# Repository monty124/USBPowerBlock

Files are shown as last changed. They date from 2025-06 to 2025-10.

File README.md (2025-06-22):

# USBPowerBlock
Tasmota controlled USB Switching

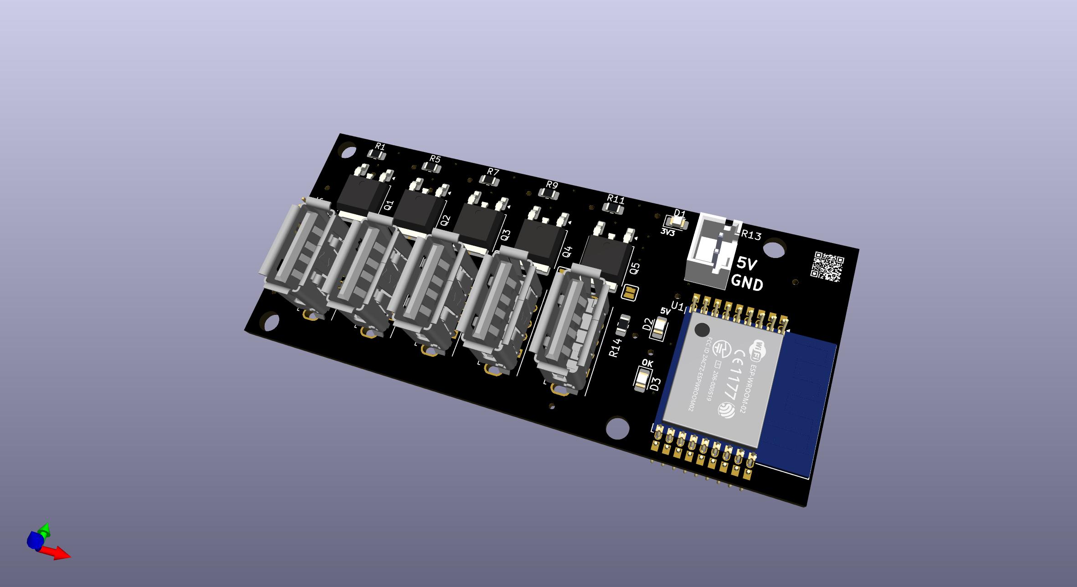
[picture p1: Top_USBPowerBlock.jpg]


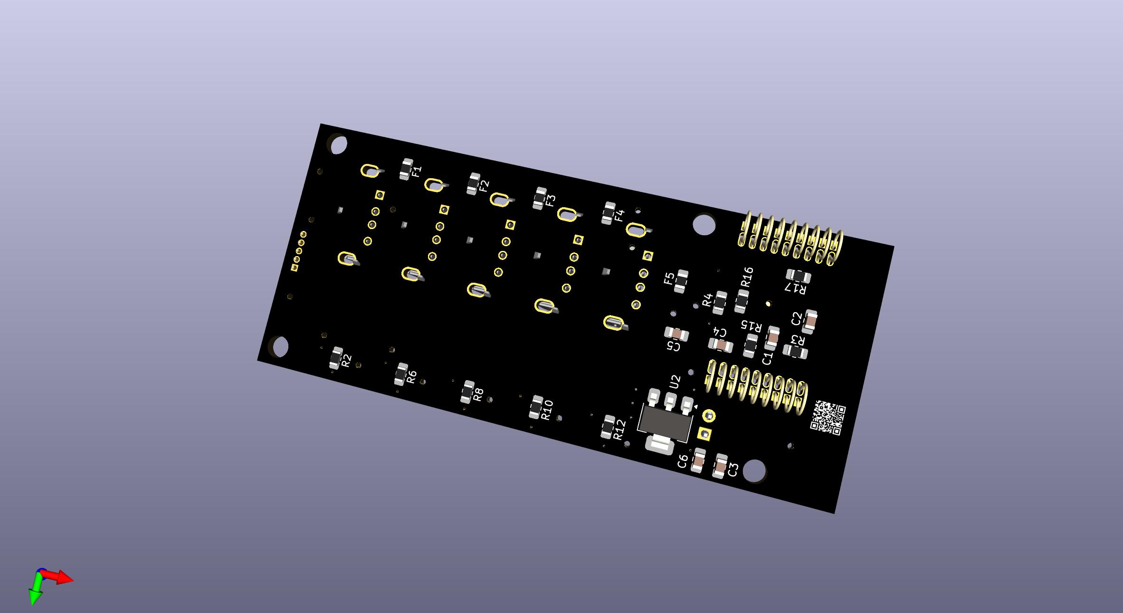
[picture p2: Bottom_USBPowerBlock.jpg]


# Why?

So many things are usb powered but can not or are not able to be integrated easily within Home Assistant; or programable.

Want to turn something on or off automatically? you will need to buy [something else](https://www.aliexpress.com/w/wholesale-TZT-sinilink-USB.html?spm=a2g0o.productlist.search.0)! and it still needs a power source

Want it to be integrated into [Home Assistant](https://www.home-assistant.io/) and or control its [privacy](https://www.voanews.com/a/east-asia-pacific_voa-news-china_cybersecurity-experts-worried-chinese-firms-control-smart-devices/6209815.html)? good luck off the shelf, you may need to [flash it](https://templates.blakadder.com/sinilink_XY-WFUSB.html) (if its supported)

Want more than one device powered from a single power source, you will need a powered hub and multiple other devices, or multiple power sources, this effectively combines 5 [sinilinks'](https://www.aliexpress.com/w/wholesale-TZT-sinilink-USB.html?spm=a2g0o.productlist.search.0) into a single unit.

It has been designed to power a device up to 500mA with the listed BOM, but is flexible (see Options below)

500mA was chosen as a default, as a 5v 2.5A/3A powesupply is very common and affordable (you probably already have one!) and this was intended to switch very low current devices (think, lights, IoT devices, etc)

For more information on USB power draw:

https://en.wikipedia.org/wiki/USB_hardware#Allowable_current_draw

Note, this does not identify itself as a PD or Battery Charging (BC) Device! (yet), technically each port should be limited to 100mA in its current design, but taking some liberties here!

# BOM

[Bill Of Materials](./USBPowerBlock_BOM.csv)

|Reference |Value |Datasheet |Qty |Product_Link|
|---|---|---|---|---|
|C1,C3,C4,C6 |0.1UF-0805-25V-_+80_-20%_|https://www.lcsc.com/datasheet/lcsc_datasheet_2304140030_TORCH-CT41G-0805-2X1-50V-0-1-F-K-N_C126469.pdf |4 |https://www.lcsc.com/product-detail/C126469.html|
|C2,C5 |10UF-0805-16V-10% |https://www.lcsc.com/datasheet/lcsc_datasheet_2409292003_Vishay-Intertech-VJ0805G106KXYTW1BC_C5334346.pdf |2 |https://www.lcsc.com/product-detail/C5334346.html|
|D1 |Blue |https://wmsc.lcsc.com/wmsc/upload/file/pdf/v2/lcsc/2208221800_TCWIN-TC0805GF01-1CSA_C5137315.pdf|1  |https://lcsc.com/product-detail/C5137315.html|
|D2 |Green|https://wmsc.lcsc.com/wmsc/upload/file/pdf/v2/lcsc/2410121920_Lite-On-LTST-C170KGKT_C98221.pdf  |1  |https://lcsc.com/product-detail/C5137315.html|
|D3 |Red  |https://wmsc.lcsc.com/wmsc/upload/file/pdf/v2/lcsc/2504101957_XINGLIGHT-XL-2012SURC_C965812.pdf |1  |https://lcsc.com/product-detail/C5137315.html|
|F1,F2,F3,F4,F5 |JK-SMD0805-020-30V |https://www.lcsc.com/datasheet/lcsc_datasheet_2007081813_Jinrui-Electronic-Materials-Co--JK-SMD0805-020-30V_C516070.pdf|5 |https://www.lcsc.com/product-detail/C516070.html|
|J1,J2,J3,J4,J5 |USB_A | Vertical USB-A |5 |https://www.aliexpress.com/item/1005005865561469.html or https://www.lcsc.com/product-detail/C456015.html|
|J6 |IO |~ |1  |~ |
|J7 |Power_In | XH2.5 |1 |https://www.aliexpress.com/item/1005003137518807.html|
|Q1,Q2,Q3,Q4,Q5 |LMAK15N10 |https://www.lcsc.com/datasheet/lcsc_datasheet_2504180925_VBsemi-Elec-ME15N10-VB_C710010.pdf |5 |https://www.lcsc.com/product-detail/C710010.html|
|R1,R3,R4,R5,R7,R9,R11,R15,R16|10KOHM-0805-1_10W-1% |https://www.lcsc.com/datasheet/lcsc_datasheet_2410121912_TyoHM-RMC080510K5-N_C269724.pdf |9 |https://www.lcsc.com/product-detail/C269724.html|
|R2,R6,R8,R10,R12 |100R |https://www.lcsc.com/datasheet/lcsc_datasheet_2411221126_UNI-ROYAL-Uniroyal-Elec-0805W8F1000T5E_C17408.pdf |5 |https://www.lcsc.com/product-detail/C17408.html|
|R13,R17|68OHM-0805-1_10W-1%|https://www.lcsc.com/datasheet/lcsc_datasheet_2410121912_TyoHM-RMC080510K5-N_C269724.pdf|2  |https://www.lcsc.com/product-detail/C269724.html|
|R14 |470OHM-0805-1_10W-1%|https://www.lcsc.com/datasheet/lcsc_datasheet_2410121912_TyoHM-RMC080510K5-N_C269724.pdf|1  |https://www.lcsc.com/product-detail/C269724.html|
|U1 |ESP-WROOM-02 |https://www.espressif.com/sites/default/files/documentation/0c-esp-wroom-02_datasheet_en.pdf |1 |https://www.lcsc.com/product-detail/C529584.html|
|U2 |AMS1117-3.3 |http://www.advanced-monolithic.com/pdf/ds1117.pdf |1 |https://www.lcsc.com/product-detail/C2992570.html|

Misc Components:

| Product | Example Link | Qty |
| --- | ---| --- |
| 5V 2.5A (min) Power Supply | https://www.wagneronline.com.au/5-volt-3a-switch-mode/power-supplies/power-lighting/smp5v-3a-21r-35234/10297/pd/ | 1 |
| Power Socket 5.5x2.1mm| https://www.aliexpress.com/item/1005002601060281.html | 1 |
| Hook Up Wire ~24AWG | https://www.aliexpress.com/item/1005007278251470.html | 1x Length Red <br> 1x Length Black |
| PCB | [Here](./USBPowerBlock/gerber) | 1 |
| Case | [Here](./Case) | 1 |
| Flexy Pins | https://core-electronics.com.au/flexypin-pack-of-100.html | 18 |

# Options

## I want more current! 

- Swap out your power adaptor for something that can supply your desired current along with approx (at least) ~250mA for the ESP
- Replace F1-F5 with a suitable current rating; 0805 package self healing fuse

  - https://www.lcsc.com/product-detail/C516070.html 500mA
  - https://www.lcsc.com/product-detail/C369151.html 1.5A
  - https://www.lcsc.com/product-detail/C2830234.html 2.2A
  
The MOSFETS are rated to approx 15A each, which is overkill.

## I don't need switched outputs but want like 5 powered USB ports

- leave all components out except J1-J5 + J7
- leave F1-F5 in (and up-rate the fuse value, see above) or replace with 0805 0 Ohm links (https://www.lcsc.com/product-detail/C96345.html)
- solder JP1-JP5
- ensure your power adaptor has enough current

# PCB

Gerber files are available to have printed

- https://www.pcbway.com/
- https://jlcpcb.com/

# 3D Printed Case

STL's are available in this repo to print or have printed

- https://www.pcbway.com/rapid-prototyping/manufacture/?type=2
- https://jlc3dp.com/?source=JLCPCB-top-productbar

# Assembly

TBC

# Tasmota

TBC

# What Next?

Some notes on desired features! (maybe, but probably not)

- Power from a 12V supply?
- Increased power outputs and PD/BC support?
- Compliant USB-C PD Power Source 
- Completed photos
- Flexypin-less design?
- ESP32-C3-WROOM design (ESP-WROOM-02 is EOL) with and without FlexyPin

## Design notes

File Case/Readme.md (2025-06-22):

Yeah this is still a WIP

Print at your own peril!

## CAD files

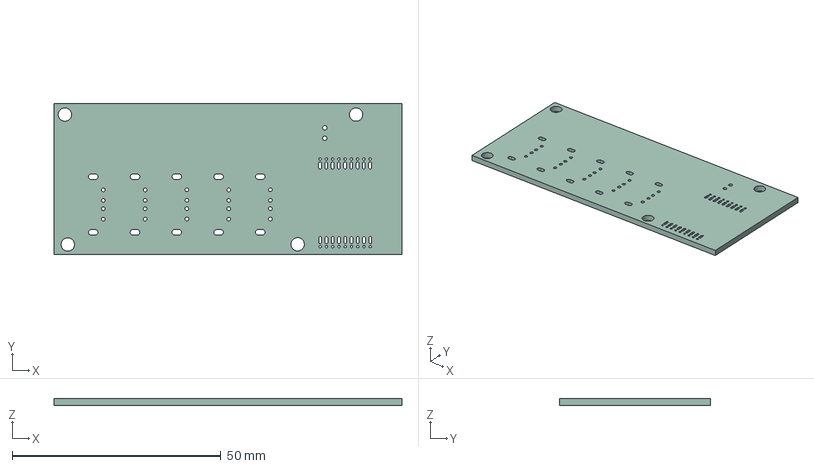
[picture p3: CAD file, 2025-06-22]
3D Models/USBPowerBlock_PCB.step
83.5 x 36.3 x 1.60 mm

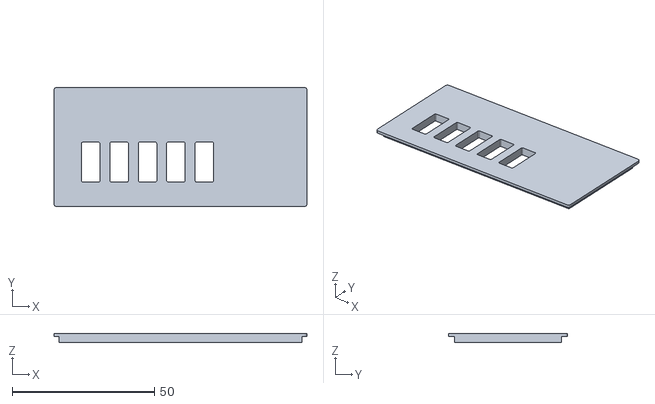
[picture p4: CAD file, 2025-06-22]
Case/USBPowerBlock Case Lid.stl
89.0 x 42.0 x 3.00

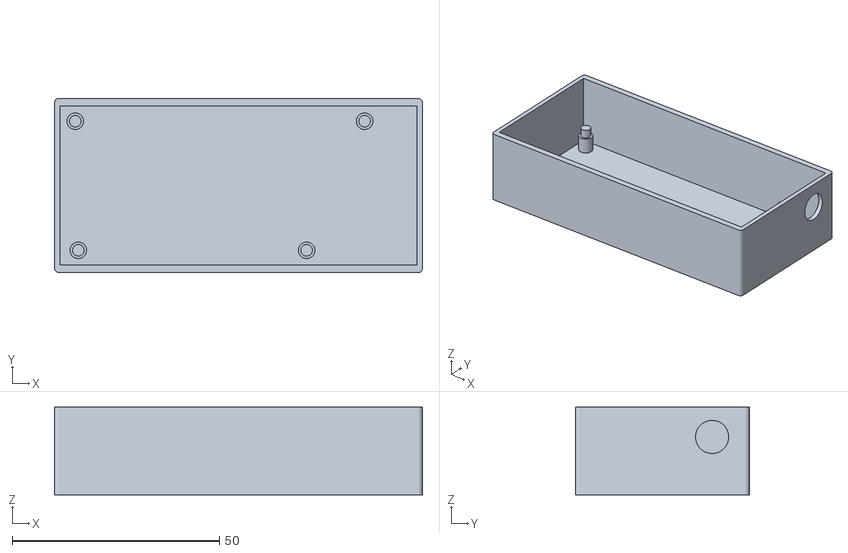
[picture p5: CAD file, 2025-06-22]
Case/USBPowerBlock Case Bottom.stl
88.8 x 42.1 x 21.2

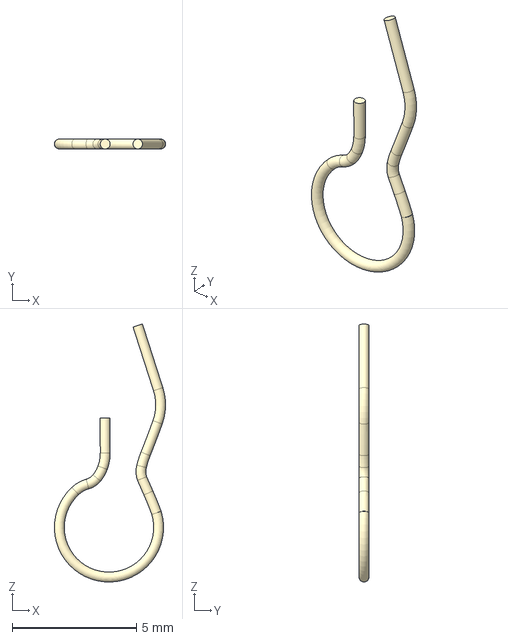
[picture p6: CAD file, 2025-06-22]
Symbols/flexypin.step
4.48 x 0.4 x 10.4 mm

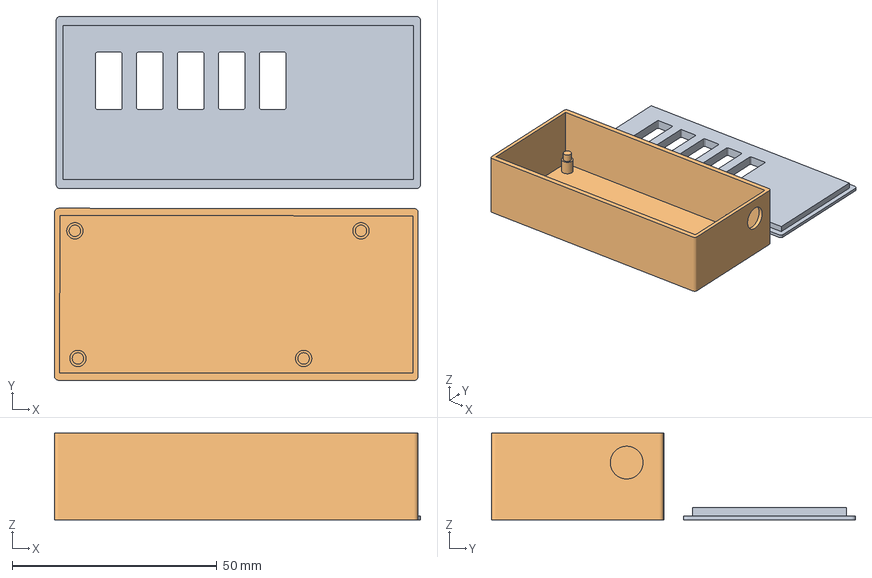
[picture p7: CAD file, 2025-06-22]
Case/USBPowerBlock Case.3mf
89.4 x 88.9 x 21.2 mm
USBPowerBlock Case Lid.stl
USBPowerBlock Case Bottom.stl

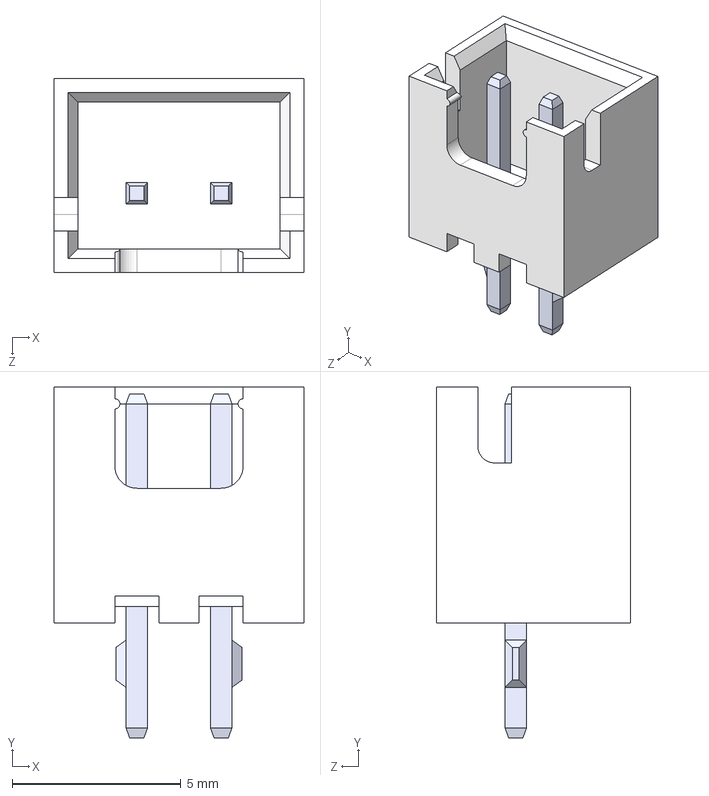
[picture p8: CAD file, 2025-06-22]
Symbols/B2B-XH-A.step
7.40 x 10.4 x 5.75 mm

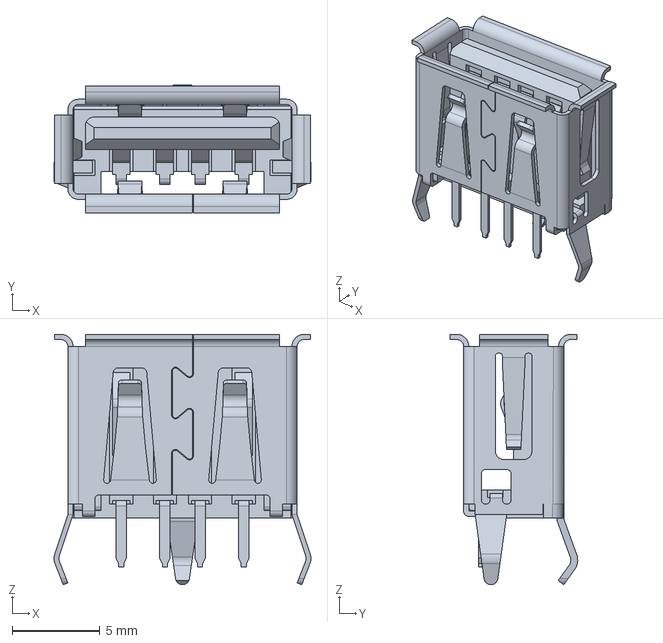
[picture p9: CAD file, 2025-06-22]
Symbols/1050570001.stp
14.7 x 7.28 x 14.3 mm

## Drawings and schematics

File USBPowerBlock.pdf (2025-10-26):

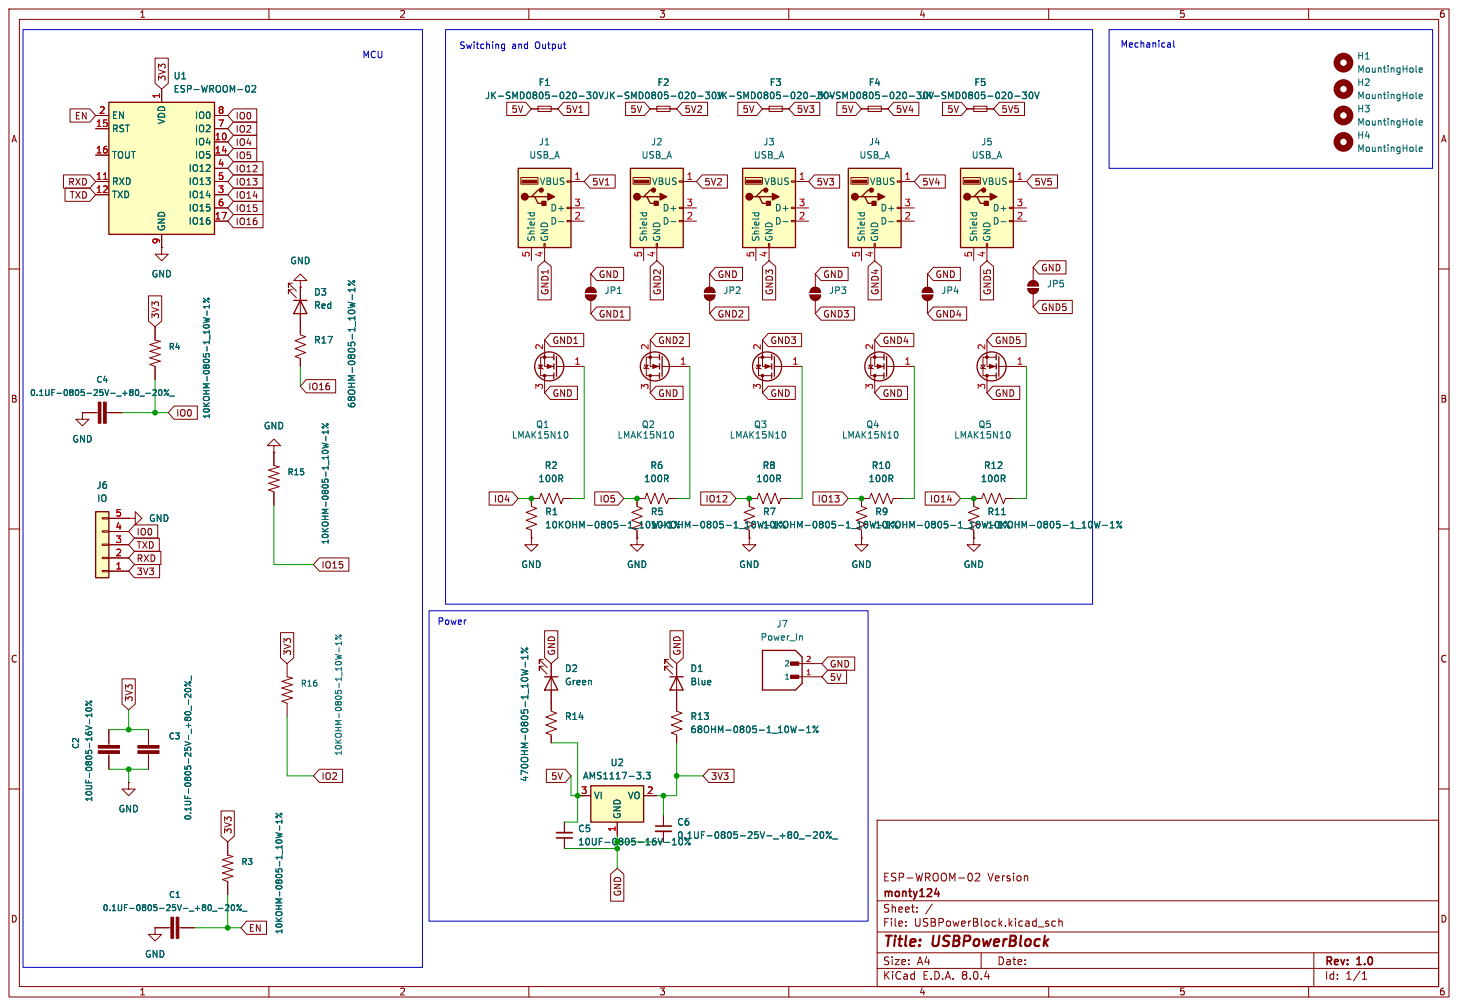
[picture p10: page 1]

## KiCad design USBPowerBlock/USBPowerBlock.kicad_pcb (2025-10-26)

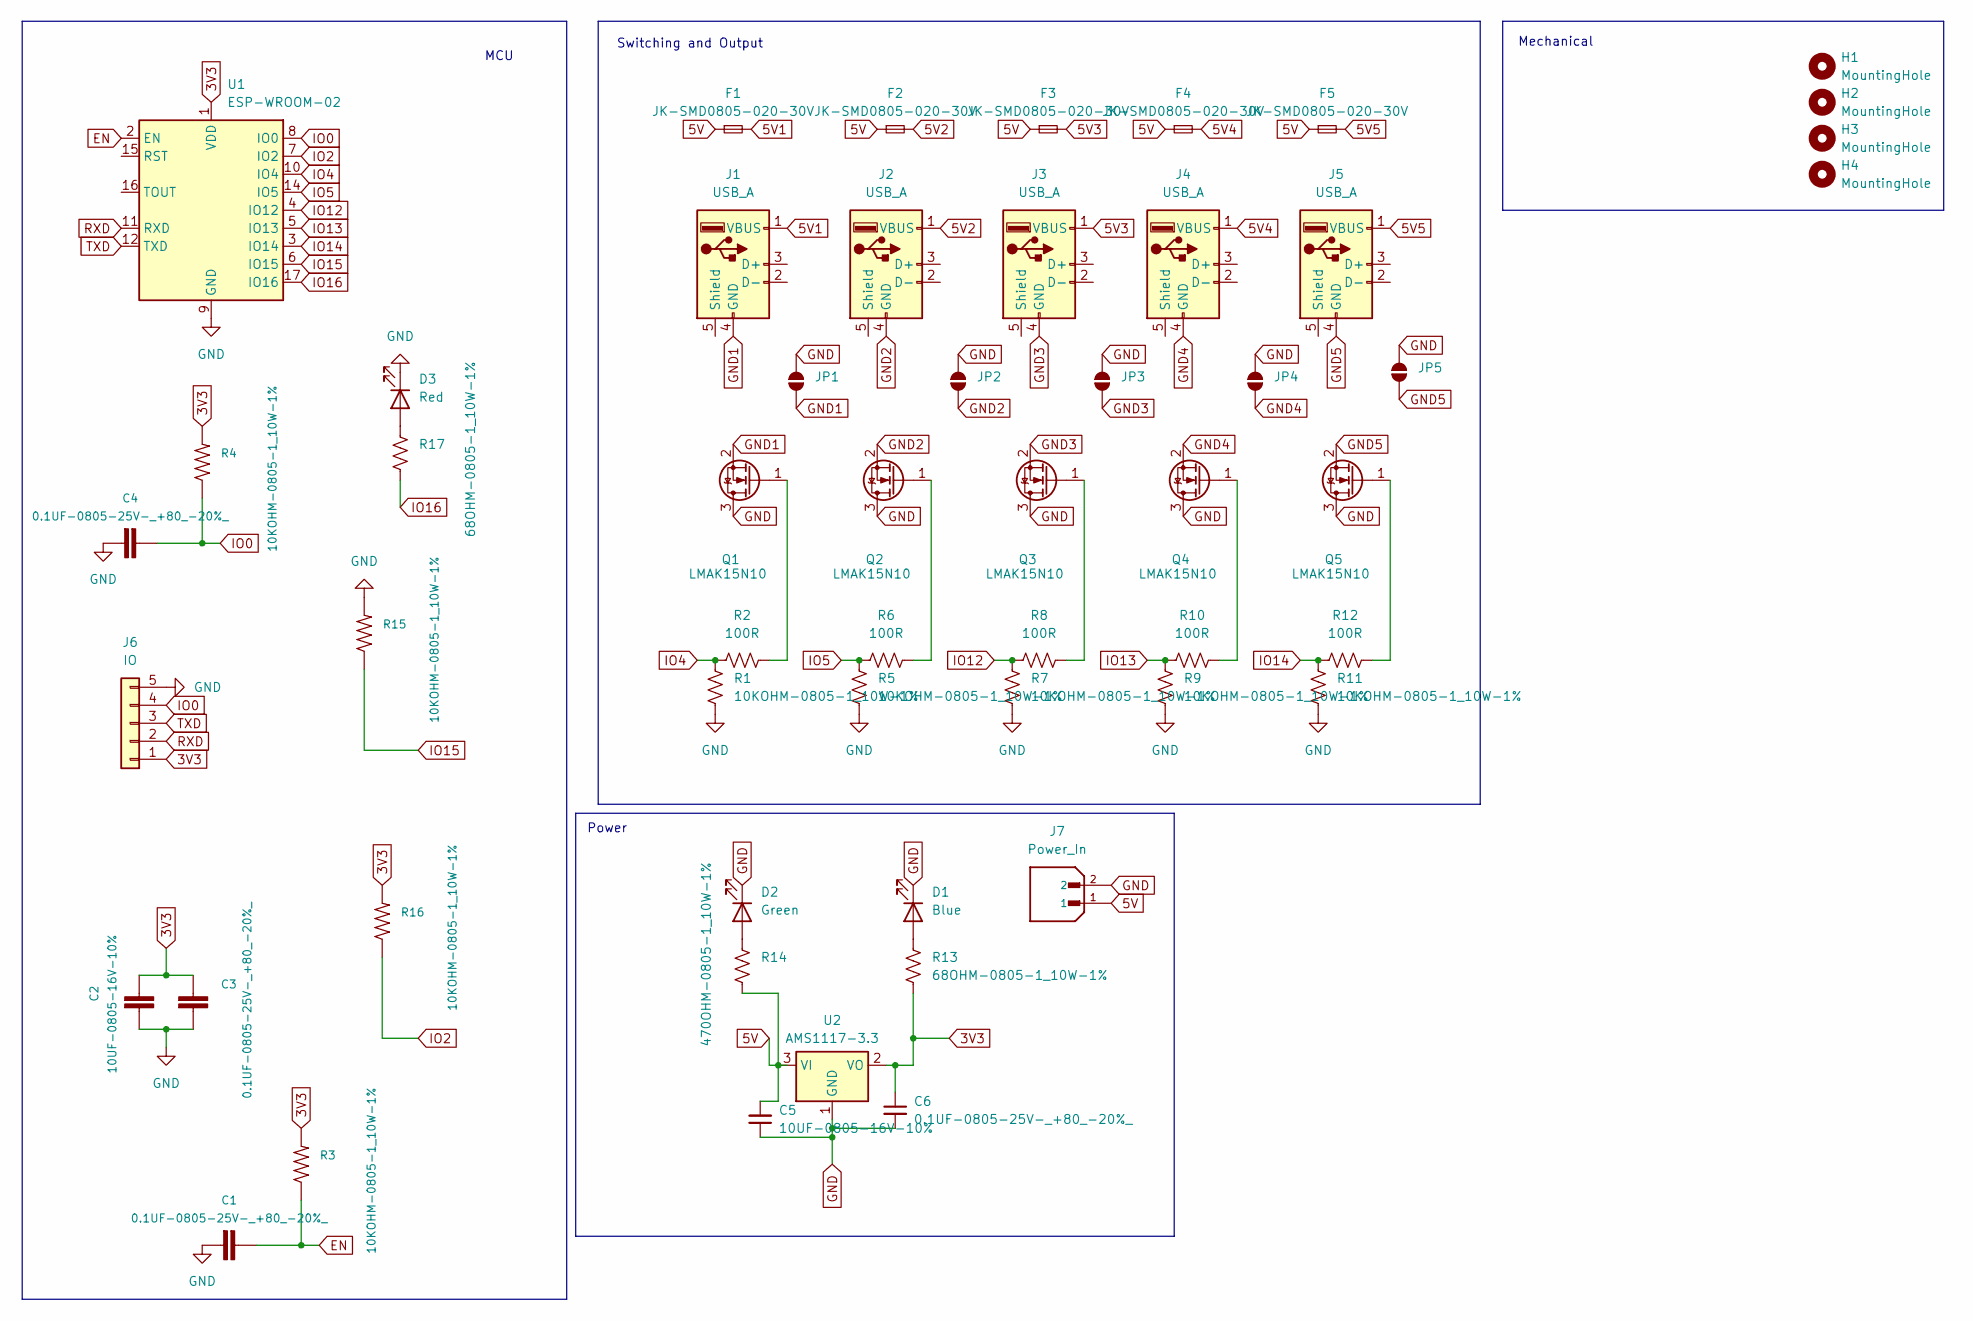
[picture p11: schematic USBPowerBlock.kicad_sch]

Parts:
C1, C3, C4, C6: 0.1UF-0805-25V-_+80_-20%_; C_0805_2012Metric_Pad1.18x1.45mm_HandSolder
C2, C5: 10UF-0805-16V-10%; C_0805_2012Metric_Pad1.18x1.45mm_HandSolder
D1: Blue; LED_0805_2012Metric_Pad1.15x1.40mm_HandSolder
D2: Green; LED_0805_2012Metric_Pad1.15x1.40mm_HandSolder
D3: Red; LED_0805_2012Metric_Pad1.15x1.40mm_HandSolder
F1, F2, F3, F4, F5: JK-SMD0805-020-30V; Fuse_0805_2012Metric_Pad1.15x1.40mm_HandSolder
H1, H2, H3, H4: MountingHole; MountingHole_3.2mm_M3
J1, J2, J3, J4, J5: USB_A; USB_11_Aliexpress
J6: IO; PinHeader_1x05_P1.27mm_Vertical
J7: Power_In; JST_B2B-XH-A; PARTREV N/A
JP1, JP2, JP3, JP4, JP5: SMT-JUMPER_2_NO_SILK
Q1, Q2, Q3, Q4, Q5: LMAK15N10; TO-252-2
R1, R3, R4, R5, R7, R9, R11, R15, R16: 10KOHM-0805-1_10W-1%; R_0805_2012Metric_Pad1.20x1.40mm_HandSolder
R2, R6, R8, R10, R12: 100R; R_0805_2012Metric_Pad1.20x1.40mm_HandSolder
R13, R17: 68OHM-0805-1_10W-1%; R_0805_2012Metric_Pad1.20x1.40mm_HandSolder
R14: 470OHM-0805-1_10W-1%; R_0805_2012Metric_Pad1.20x1.40mm_HandSolder
U1: ESP-WROOM-02; ESP-WROOM-02-Flexy
U2: AMS1117-3.3; SOT-223-3_TabPin2

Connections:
3V3: C2.1, C3.1, C6.1, J6.1, R3.2, R4.2, R13.1, R16.2, U1.1 (VDD), U2.2 (VO)
5V: C5.2, F1.1, F2.1, F3.1, F4.1, F5.1, J7.1, R14.1, U2.3 (VI)
5V1: F1.2, J1.1 (VBUS)
5V2: F2.2, J2.1 (VBUS)
5V3: F3.2, J3.1 (VBUS)
5V4: F4.2, J4.1 (VBUS)
5V5: F5.2, J5.1 (VBUS)
EN: C1.1, R3.1, U1.2 (EN)
GND: C1.2, C2.2, C3.2, C4.2, C5.1, C6.2, D1.1 (K), D2.1 (K), D3.1 (K), J6.5, J7.2, JP1.2 (B), JP2.2 (B), JP3.2 (B), JP4.2 (B), JP5.2 (B), Q1.3 (D), Q2.3 (D), Q3.3 (D), Q4.3 (D), Q5.3 (D), R1.1, R5.1, R7.1, R9.1, R11.1, R15.2, U1.9 (GND), U1.13 (GND), U1.18 (GND), U1.19 (GND), U2.1 (GND)
GND1: J1.4 (GND), JP1.1 (A), Q1.2 (S)
GND2: J2.4 (GND), JP2.1 (A), Q2.2 (S)
GND3: J3.4 (GND), JP3.1 (A), Q3.2 (S)
GND4: J4.4 (GND), JP4.1 (A), Q4.2 (S)
GND5: J5.4 (GND), JP5.1 (A), Q5.2 (S)
IO0: C4.1, J6.4, R4.1, U1.8 (IO0)
IO2: R16.1, U1.7 (IO2)
IO4: R1.2, R2.1, U1.10 (IO4)
IO5: R5.2, R6.1, U1.14 (IO5)
IO12: R7.2, R8.1, U1.4 (IO12)
IO13: R9.2, R10.1, U1.5 (IO13)
IO14: R11.2, R12.1, U1.3 (IO14)
IO15: R15.1, U1.6 (IO15)
IO16: R17.1, U1.17 (IO16)
unnamed: D1.2 (A), R13.2
unnamed: D2.2 (A), R14.2
unnamed: D3.2 (A), R17.2
unnamed: Q1.1 (G), R2.2
unnamed: Q2.1 (G), R6.2
unnamed: Q3.1 (G), R8.2
unnamed: Q4.1 (G), R10.2
unnamed: Q5.1 (G), R12.2
RXD: J6.2, U1.11 (RXD)
TXD: J6.3, U1.12 (TXD)

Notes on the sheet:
Mechanical
Power
MCU
Switching and Output

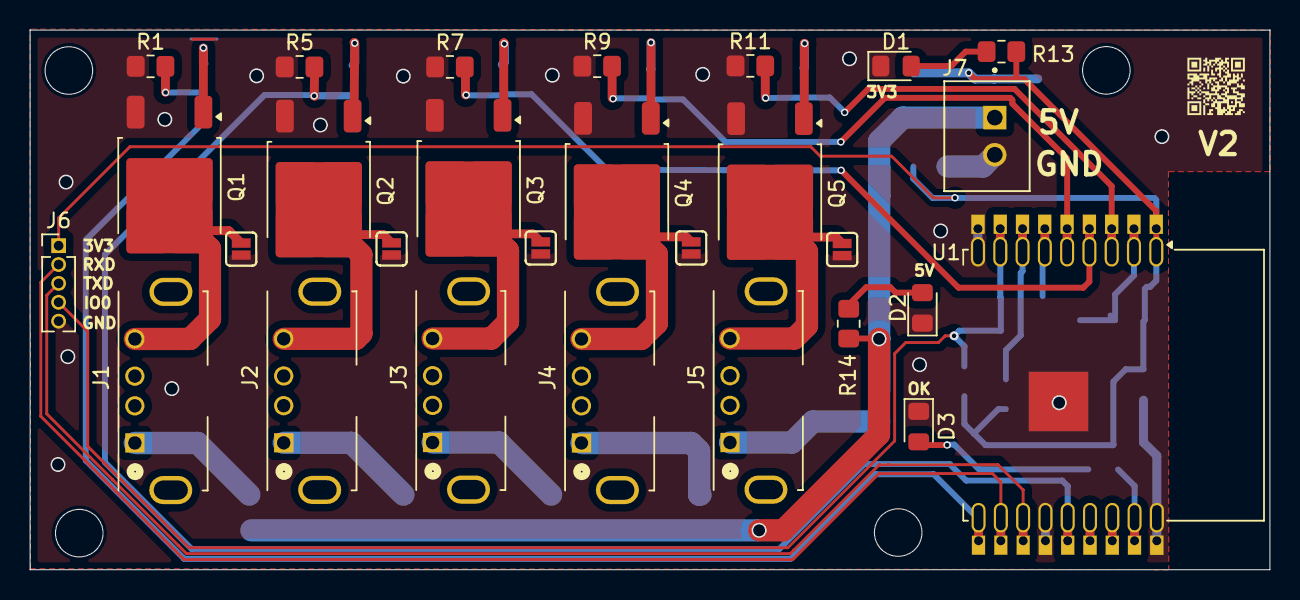
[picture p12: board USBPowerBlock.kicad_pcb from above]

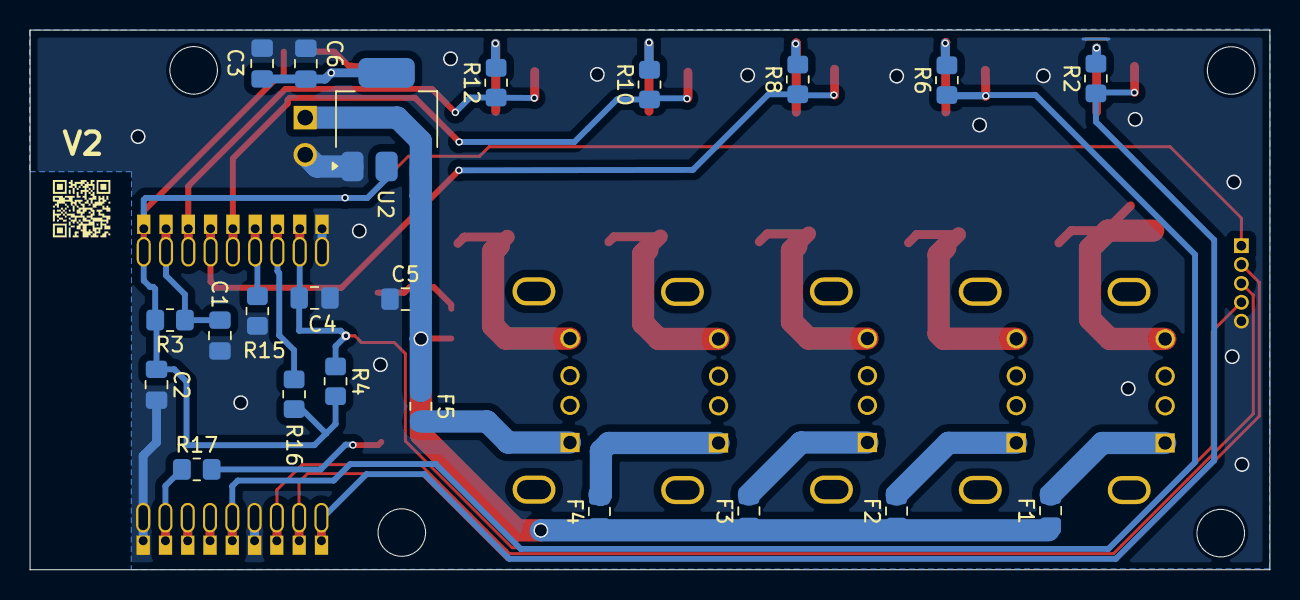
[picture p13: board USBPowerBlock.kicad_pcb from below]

Board: 2 copper layers, 83.5 x 36.3 mm, 54 parts (22 on the bottom side), 33 nets.

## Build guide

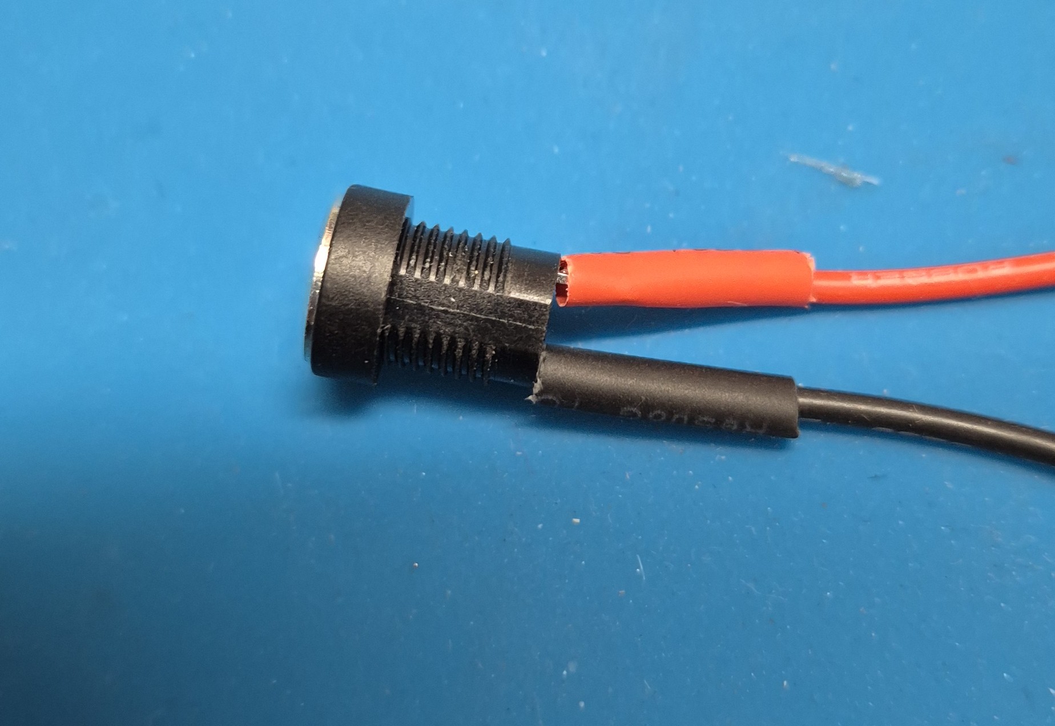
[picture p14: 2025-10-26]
Assembly/20251019_125322.jpg

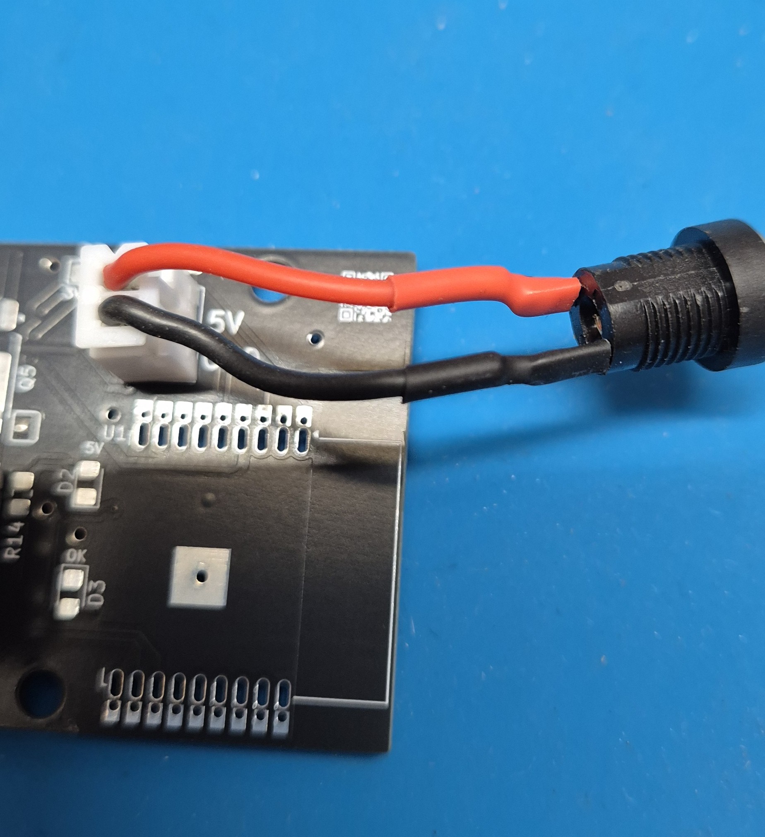
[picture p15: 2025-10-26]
Assembly/20251019_130838.jpg

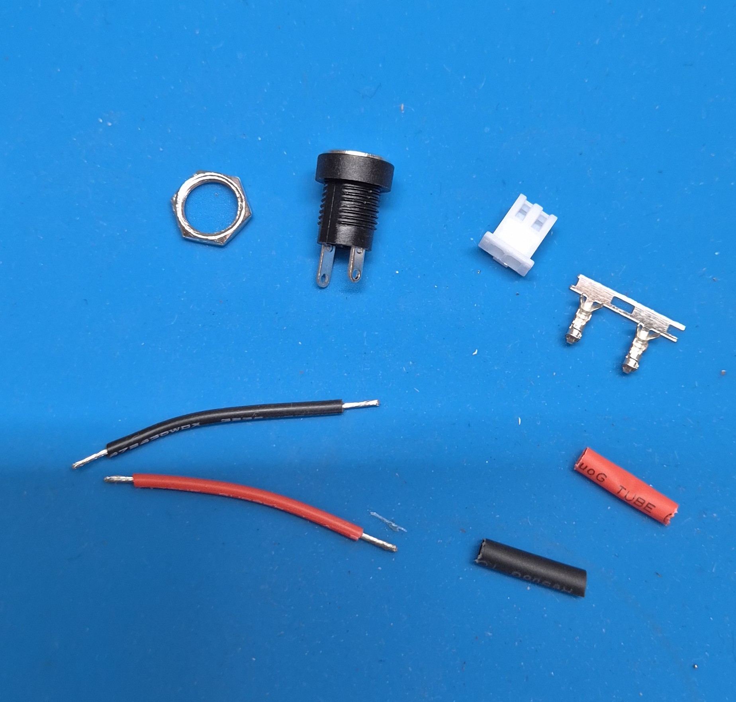
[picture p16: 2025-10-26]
Assembly/20251019_125116.jpg

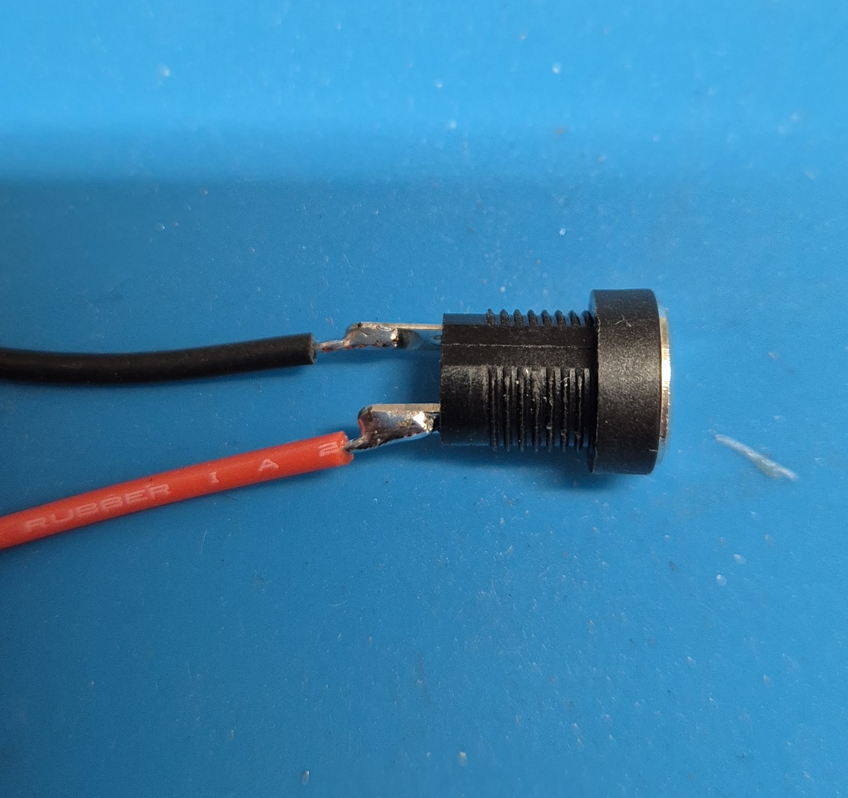
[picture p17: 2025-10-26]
Assembly/20251019_125239.jpg

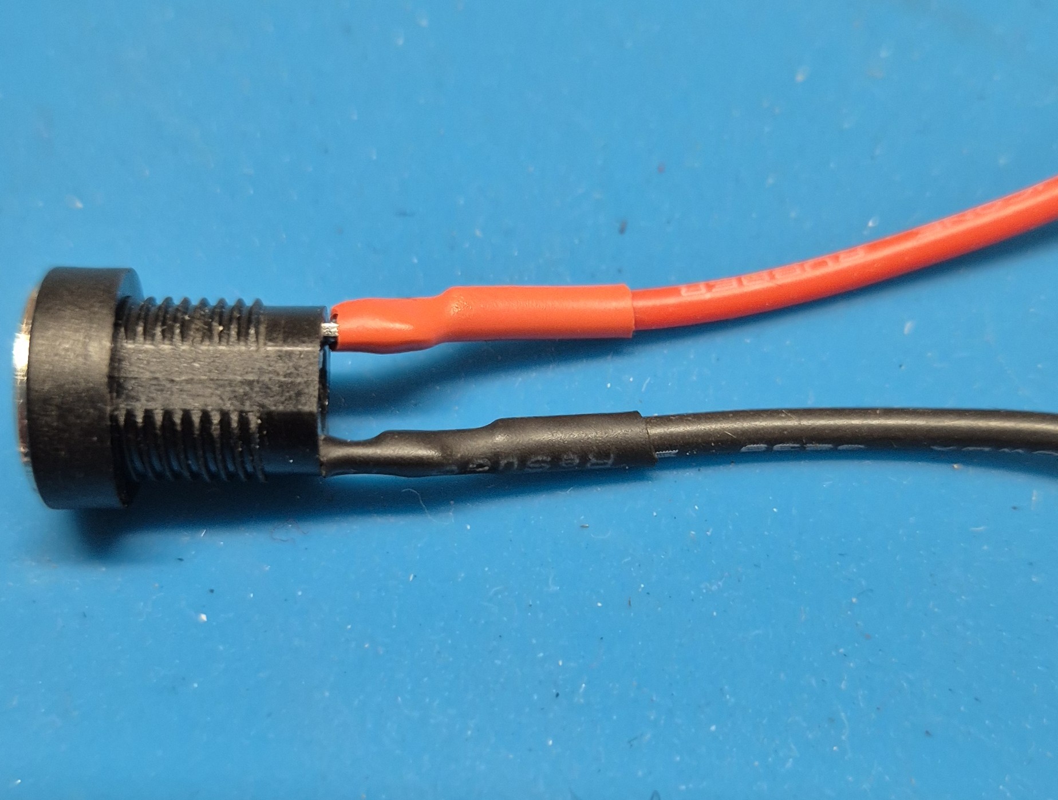
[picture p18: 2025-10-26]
Assembly/20251019_125403.jpg

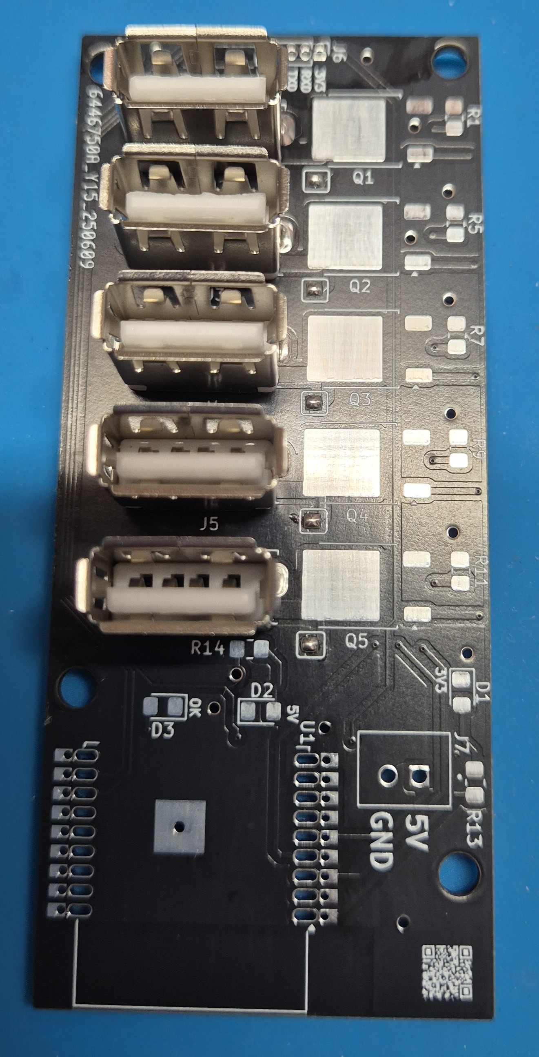
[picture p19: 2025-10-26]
Assembly/20251019_124036.jpg

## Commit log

2025-06-22 initial commit - v1
    initial commit for version 1
    [1050570001.stp, B2B-XH-A.step, USBPowerBlock Case Lid.stl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]
2025-10-26 V2
    Fix for V2 stuff up and Assembly Photos
    [USBPowerBlock-B_Cu.gbr, USBPowerBlock-B_Mask.gbr, USBPowerBlock-B_Paste.gbr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]
